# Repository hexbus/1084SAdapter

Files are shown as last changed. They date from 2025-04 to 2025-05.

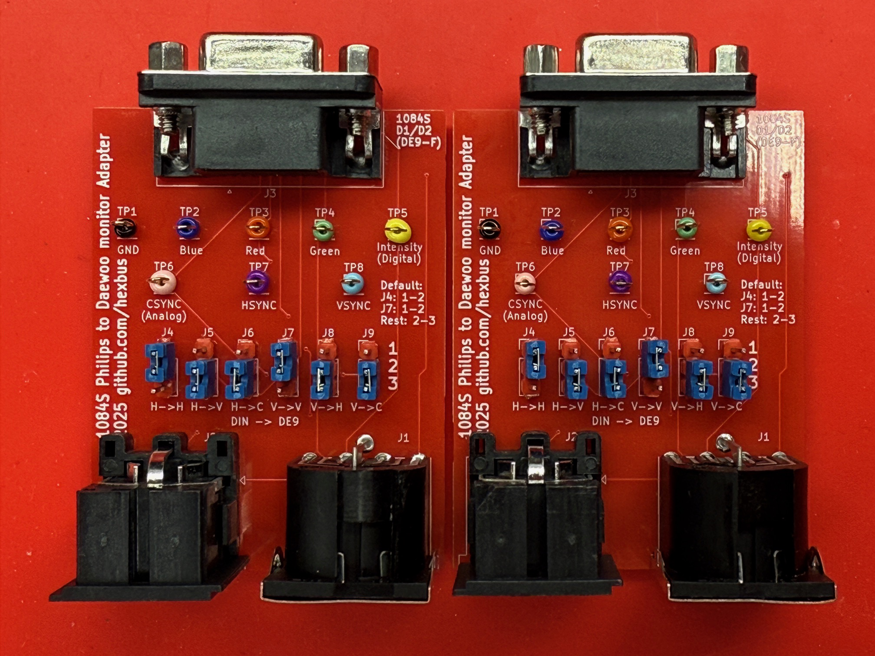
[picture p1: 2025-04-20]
1084s-adapter.JPG

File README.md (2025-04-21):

# 1084SAdapter
Universal 1084S Monitor Adapter – DIN ↔ DE9 RGB Adapter/Monitor for Amiga, Tandy, and analog/digital RGB 1980's computers

**Philips DIN ↔ Daewoo DE9 Converter and signal debugger/monitor**

This board adapts between different 1084S monitor standards—commonly found in Philips and Daewoo variants—and allows flexible signal routing for Amiga, CGA-based PCs, and other retro systems.

1084s-adapter

---

## 🌟 Key Features & Use Cases

This board supports multiple configurations on a 1084S monitor (Magnavox, Philips, etc) from the 1980s and early 1990s:

1. **Philips (DIN-based) to traditional Amiga (DE9)**  
   Use this to connect a DIN-based 1084 monitor (typically Philips) to an Amiga that outputs via DE9 monitor cable.

2. **Daewoo (DE9-based) to traditional Amiga (Analog RGB DIN)**  
   Use this to connect a DE9-based 1084 monitor (typically Daewoo) to an Amiga that outputs via DIN monitor cable.

3. **Cross-compatibility**  
   Adapt any other computer using these connectors to a 15kHz monitor, including hybrid setups.
   (Like a Myarc Geneve 9640 to a 1084S-D1/D2, or a MSX to a 1084S-D1/D2 that had a DIN connection.)

5. **CGA (Tandy 1000) to Philips 1084S (Digital RGB DIN)**  
   Use this board to easily connect DE9 CGA-based PCs to a digital DIN-based monitor like the Philips 1084.  
6. **Real-time signal troubleshooting**  
   Connect two boards back-to-back to test sync and RGB lines without format conversion:  
   ```
   Monitor (Analog RGB input) 
     <-> DIN6 male-male cable 
     <-> Adapter Board 
     <-> DE9 male-male cable 
     <-> Adapter Board 
     <-> DIN6 male (Amiga cable/Amiga)
   ```

7. **Signal analysis and custom monitor adapter testing**  
   Use an oscilloscope with this board while designing new adapters or troubleshooting pinouts by experimenting with sync jumper configurations.  Monitor all sync and RGB lines, and see if you're getting the output you're expecting on all lines.  Helps with troubleshooting no-output situations, and if it's a computer fault, or a monitor fault.

---

## ⚠️ Warning

This board gives you *a lot* of flexibility—but with that comes responsibility.  
Incorrect jumper settings, especially for sync signals, can **damage your monitor**. Be **absolutely certain** you understand what you're doing when adjusting jumper settings (J4–J9). You assume all risk for damage caused by improper usage.

---

## 🔧 Default Configuration

Out of the box, the board routes Horizontal and Vertical Sync directly:

- **J4 (HSYNC)**: Enabled → Position **1–2**  
- **J7 (VSYNC)**: Enabled → Position **1–2**

---

## 🧩 Jumper Reference (Sync Routing)

Use these jumpers to customize how sync signals are routed:

| Jumper | Signal Routed From (DIN) | To (DE9) Pin | Enabled When | Notes |
|---|---|---|---|---|
| **J4** | HSYNC | HSYNC | 1–2 | **Default ON** |
| **J5** | HSYNC | VSYNC | 1–2 | Optional, disabled  |
| **J6** | HSYNC | CSYNC | 1–2 | Optional, disabled  |
| **J7** | VSYNC | VSYNC | 1–2 | **Default ON** |
| **J8** | VSYNC | HSYNC | 1–2 | Optional, disabled  |
| **J9** | VSYNC | CSYNC | 1–2 | Optional, disabled |

(All jumpers can be stowed in position 2-3 when disabled.)

**Note:** Only enable the jumpers that suit your configuration. Never enable conflicting signals unless you're absolutely sure.

### Example (Hypothetical Scenario):
You have a monitor that **only accepts CSYNC**, but your system provides separate HSYNC and VSYNC via DIN.  
You might try:
- Enable **J9**: VSYNC → CSYNC  
- Optionally enable **J6**: HSYNC → CSYNC  
⚠️ This is theoretical; test carefully and monitor your signals.

---

## 🛒 Bill of Materials (BOM)

| Designator | Part Number / Description |
|---|---|
| **J1** | TE Connectivity 5211511-1 (DIN-8) or equivalent |
| **J2** | TE Connectivity 9-211509-0 (DIN-6) or equivalent |
| **J3** | DE9 Female, Right Angle, 2.77×2.84 mm pins, 7.48 mm offset |
| **J4–J9**  | 3-pin standard 2.54 mm headers (6 × 3 = 18 pins total) |
| **TP1–TP8**| Test points (fit standard 2.54 mm header holes) |

---

## 📌 Connector Pinouts

These are the relevant pinouts for the **Commodore 1084S** monitor. Understanding these is critical for properly wiring and configuring sync routing via jumpers (J4–J9).

---

### 🔌 J1 – Digital RGB Input (DIN-8, typically Philips models)

| Pin | Name | Description |
|-----|---|---|
| 1 | n/c | Not connected |
| 2 | R | Red |
| 3 | G | Green |
| 4 | B | Blue |
| 5 | I | Intensity |
| 6 | GND | Ground |
| 7 | HSYNC  | Horizontal Sync |
| 8 | VSYNC  | Vertical Sync |

---

### 🎨 J2 – Analog RGB Input (DIN-6, typically for Amiga or other analog video sources)

| Pin | Name | Description |
|-----|---|---|
| 1 | G | Green |
| 2 | HSYNC  | Horizontal Sync |
| 3 | GND | Ground |
| 4 | R | Red |
| 5 | B | Blue |
| 6 | VSYNC  | Vertical Sync |

---

### 🖥️ J3 – DE9 Video Connector (Female, at Monitor)

This connector supports **both analog and digital RGB**, combining signals from the DIN connectors internally.

| Pin | Name | Analog Mode | Digital Mode |
|-----|---|---|---|
| 1 | GND | Ground | Ground |
| 2 | GND | Ground | Ground |
| 3 | R | Red | Red |
| 4 | G | Green | Green |
| 5 | B | Blue | Blue |
| 6 | I | *Not Connected* | Intensity |
| 7 | CSYNC  | Composite Sync | *Not Connected* |
| 8 | HSYNC  | *Not Connected* | Horizontal Sync |
| 9 | VSYNC  | *Not Connected* | Vertical Sync |

📝 **Note:** The 1084S DE9 connector internally combines analog and digital signals from the two DIN connectors. That’s why this board can act as a bidirectional adapter between Philips-style and Daewoo-style 1084S monitors.

---

## 📷 Diagrams & Visuals

Pinout diagrams (DIN-6, DIN-8, and DE9) coming soon!

Commodore_1084_pinout_DIN-rotated_large


---

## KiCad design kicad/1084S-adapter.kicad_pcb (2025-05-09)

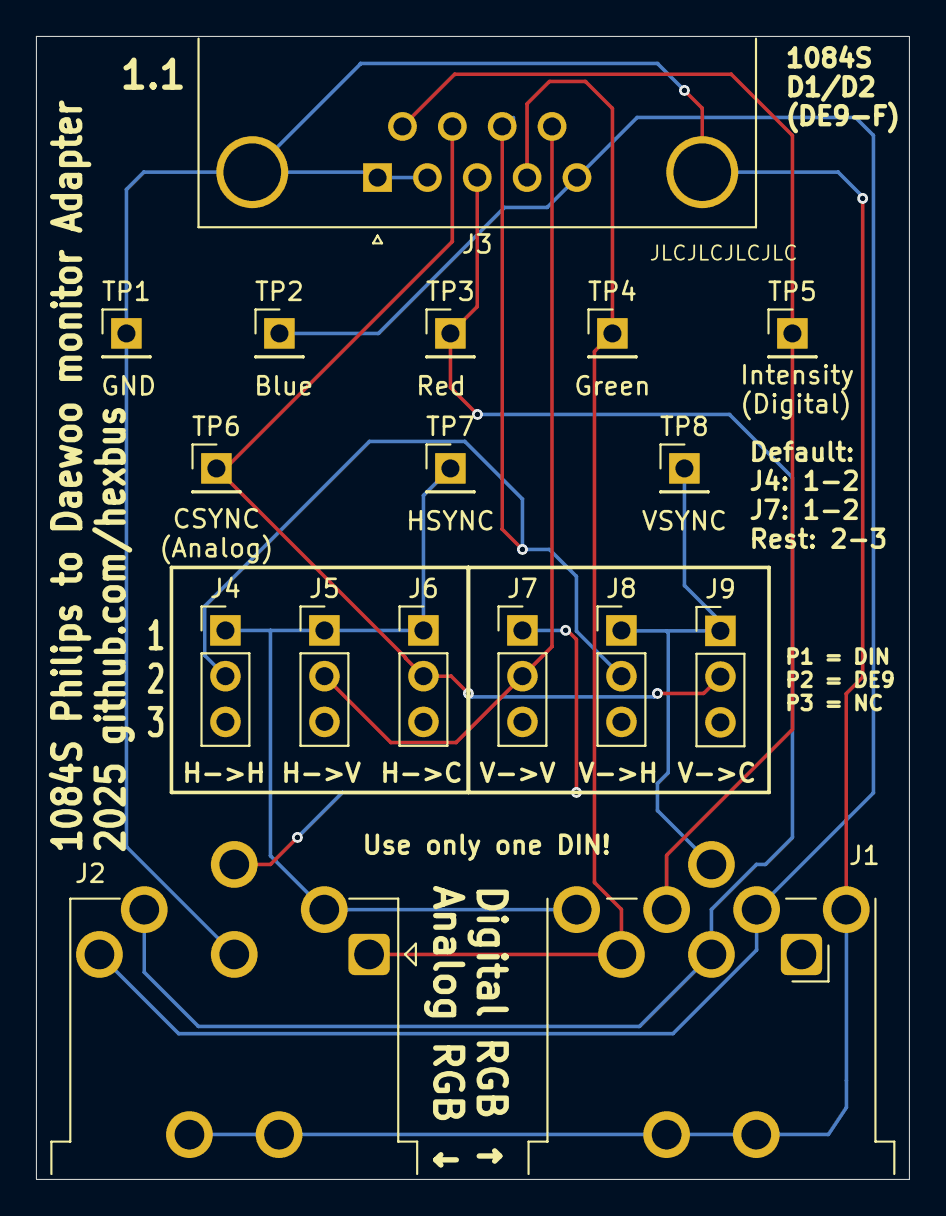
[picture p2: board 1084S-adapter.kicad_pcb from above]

Board: 2 copper layers, 48.5 x 63.5 mm, 17 parts (0 on the bottom side), 10 nets.

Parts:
J1: TE_5211511-1_DIN-8_Circular
J2: TE_9-211509-0_DIN-6_Circular
J3: Connector_Dsub:DSUB-9_Female_Horizontal_P2.77x2.8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; DSUB-9_Female_Horizontal_P2.77x2.84mm_EdgePinOffset4.94mm_H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
J4: H->H; PinHeader_1x03_P2.54mm_Vertical
J5: H->V; PinHeader_1x03_P2.54mm_Vertical
J6: H->C; PinHeader_1x03_P2.54mm_Vertical
J7: V->V; PinHeader_1x03_P2.54mm_Vertical
J8: V->H; PinHeader_1x03_P2.54mm_Vertical
J9: V->C; PinHeader_1x03_P2.54mm_Vertical
TP1: P1+2 GND; PinHeader_1x01_P2.54mm_Vertical
TP2: Pin 5 Blue; PinHeader_1x01_P2.54mm_Vertical
TP3: Pin 3 RED; PinHeader_1x01_P2.54mm_Vertical
TP4: Pin 4 GREEN; PinHeader_1x01_P2.54mm_Vertical
TP5: P6 Intensity (Dig); PinHeader_1x01_P2.54mm_Vertical
TP6: Pin 7 CSYNC (Ana); PinHeader_1x01_P2.54mm_Vertical
TP7: Pin 8 HSYNC; PinHeader_1x01_P2.54mm_Vertical
TP8: Pin 9 VSYNC; PinHeader_1x01_P2.54mm_Vertical

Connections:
/BLUE: J1.4, J2.5, J3.5, TP2.1
/CSYNC9: J3.7, J6.2, J9.2, TP6.1
/GND: J1.0, J1.6, J2.0, J2.3, J3.0 (PAD), J3.1, J3.2, TP1.1
/GREEN: J1.3, J2.1, J3.4, TP4.1
/HSYNC: J1.7, J2.2, J4.1, J5.1, J6.1, TP7.1
/INTENSITY: J1.5, J3.6, TP5.1
/RED: J1.2, J2.4, J3.3, TP3.1
/VSYNC: J1.8, J2.6, J7.1, J8.1, J9.1, TP8.1
HSYNC9: J3.8, J4.2, J8.2
VSYNC9: J3.9, J5.2, J7.2
